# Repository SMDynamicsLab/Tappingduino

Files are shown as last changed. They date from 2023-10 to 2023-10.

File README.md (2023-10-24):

# Tappingduino
## A versatile shield for paced finger tapping experiments with Arduino

Paula Caral [1], Tomás Correa Morales [1], Paz García Lodi Fe [1], Ariel D. Silva [2,4], Ulises Bussi [2], Ignacio Spiousas [3,4], and Rodrigo Laje [2,4]

[1] Departamento de Física, FCEN, Universidad de Buenos Aires, Argentina  
[2] Laboratorio de Dinámica Sensomotora, Departamento de Ciencia y Tecnología, Universidad Nacional de Quilmes, Argentina  
[3] Laboratorio del Tiempo y la Experiencia, Universidad de San Andrés, Argentina  
[4] CONICET, Argentina

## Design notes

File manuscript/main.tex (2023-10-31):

    \documentclass[twocolumn]{article}

\usepackage{amsmath}
\usepackage{amssymb}
\usepackage{graphicx}
\usepackage{float}
\usepackage{bm}
\usepackage{wrapfig}
\usepackage{hyperref}
\usepackage{authblk}
\usepackage[backend=biber, sorting=none, style=numeric-comp]{biblatex}
\addbibresource{biblio.bib}

\title{Tappingduino: A versatile shield for paced finger tapping experiments with Arduino}
\author[1]{Paula Caral}
\author[1]{Tomás Correa Morales}
\author[1]{Paz García Lodi Fe}
\author[2,4]{Ariel D. Silva}
\author[2]{Ulises Bussi}
\author[3,4]{Ignacio Spiousas}
\author[2,4]{Rodrigo Laje}
\affil[1]{\small Departamento de Física, FCEN, Universidad de Buenos Aires, Argentina}
\affil[2]{Laboratorio de Dinámica Sensomotora, Departamento de Ciencia y Tecnología, Universidad Nacional de Quilmes, Argentina}
\affil[3]{Laboratorio del Tiempo y la Experiencia, Universidad de San Andrés, Argentina}
\affil[4]{CONICET, Argentina}

\date{\today}

\begin{document}

\maketitle

\begin{abstract}
Paced finger tapping is the simplest task to study sensorimotor synchronization (SMS), that is the mostly specifically human behavior of synchronizing motor actions to an external metronome \cite{Bavassi2013,Bavassi2017,Repp2005,Repp2013}.

In this work we show the design and construction of an Arduino shield for paced finger-tapping experiments. The pin footprint is compatible with Arduino Mega 2560 \cite{arduinomega}.
\end{abstract}

\section{System specifications}

The device is intended to be versatile and to allow many different types of experimental conditions, all related to the paced finger-tapping task.

\begin{description}
    \item[Independent audio channels.] Auditory stimuli are extensively used in finger tapping experiments. This device would allow experiments with dichotic auditory stimuli, not only for the study of time processing in healthy subjects \cite{Piazza1977} but also for the study of several perceptual and motor disorders \cite{Hugdahl1989}, cognitive impairments, and diseases \cite{Sebaiti2022}.

    \item[Sound timbre.] Control of sound quality or timbre is important in some experimental designs, for example choosing the sound waveform to be a square wave, a sinusoidal wave, etc.

    \item[Noise masking.] In order to better control the auditory feedback from the tap itself it is important to have good quality headphones, and use noise masking. White noise generation capabilities are thus desirable.
    
    \item[Virtual ground.] Arduino is a single-supply device, that is it only uses 0 and 5 V supply rails. Audio signals, however, oscillate above and below a reference. A virtual ground is thus needed at a value of approximately 2.5 V to allow the audio signals to oscillate around it.
    
    \item[Force sensor.] Responses are detected by a force-sensitive resistor (FSR). Some experimental designs need two of them \cite{Versaci2021} so this is also a requirement.
    
    \item[Visual stimuli.] Experimental designs to study sensory and sensorimotor integration need the stimuli to have at least two different modalities. This is why we included two LEDs in the device.

    \item[Temporal alignment.] Simultaneous recording of EEG data is now very usual in finger tapping experiments. A connector is included to allow a one-way, 3-bit alignment signal between Arduino and a second recording device.

    \item[Servo driving.] Some experimental designs include {\em spatial} perturbations in addition to the usual temporal ones \cite{Lopez2019}. This is why we include connectors to drive two servos.
\end{description}

\section{Hardware}

\subsection{Circuit design}

We designed the circuit under the constraint that all op amps should be single-supply (LM324) so the shield is fully compatible with the voltage range of Arduino. There are several technical reports available with recommendations and design criteria for single-supply op amp circuits \cite{singlesupply2000}.

We used Eagle, a well-known electronic design automation software for schematic creation and editing, auto-routing, and PCB layout. The circuit was tested on protoboard before printing and soldering. Figure \ref{fig.schematic} shows the circuit schematic.

\subsubsection{Virtual ground}

Block 1 in Figure \ref{fig.schematic} is a standard design of a virtual ground: a voltage divider with an op amp in a follower configuration \cite{singlesupply2000}. This allows us to decouple the voltage divider from the rest of the circuit (ideal voltage divider). An additional capacitor helps filtering out high-frequency noise.

\subsubsection{Independent audio channels}

Block 2 in Figure \ref{fig.schematic} contains the two independent audio channels A and B (left and right, respectively). Each channel has an op amp in a variable-gain, summing amplifier configuration. Each summing amplifier has three inputs corresponding to stimulus, feedback, and noise. Each input signal comes from a different output pin in the Arduino and enters a voltage divider prior to the summing amplifier to prevent saturation. The variable gain is controlled by a dual potentiometer and allows the subject to adjust the sound volume. The reference voltage for the summing amplifier is virtual ground. Resistor values were chosen so that the impedance at each stage in the chain divider-summing-amplifier is an order of magnitude greater than the previous stage (10 k$\Omega$, 100 k$\Omega$, 1 M$\Omega$), thereby reducing unwanted currents and voltage drops.

\subsubsection{Alignment, visual stimuli, and servos}

Block 3 in Figure \ref{fig.schematic} includes a 3-pin connector for sending a temporal alignment signal to other devices, two LEDs for the delivery of visual stimuli, and two 3-pin connectors for driving two servos.

\subsubsection{Force sensors}

Block 4 in Figure \ref{fig.schematic} shows the connectors for the two force sensors. Each sensor has a potentiometer (trimpot) to adjust the circuit's sensitivity so it can either detect a soft tap (i.e.\ a low-voltage signal) or prevent a strong tap from saturating (i.e.\ a high-voltage signal).

\subsubsection{Low-pass filtering}

We decided not to include a low-pass filter due to space constraints: two additional op amps would be needed (one for each audio channel), meaning a whole additional integrated circuit plus its connections, in addition to resistors and capacitors. As shown below (Figure \ref{fig.BRDCompleto}), the PCB is already very crowded for hand soldering and a double-sided copper-clad laminate was necessary to accommodate all traces. However, noise generation capabilities are included as described above; in case noise is desired, an external low-pass filter should be added between the audio output of the shield and the headphones.

\begin{figure*}[!ht]
    \centering
    
    \caption{Circuit schematic. Block 1: virtual ground. Block 2: independent audio channels. Block 3: temporal alignment, visual stimuli, and servo driving. Block 4: force sensor connectors. Pin A11 is used as analog input to record the actual value of virtual ground and making it available to the code.}
    \label{fig.schematic}
\end{figure*}

\begin{figure*}[!ht]
    \centering
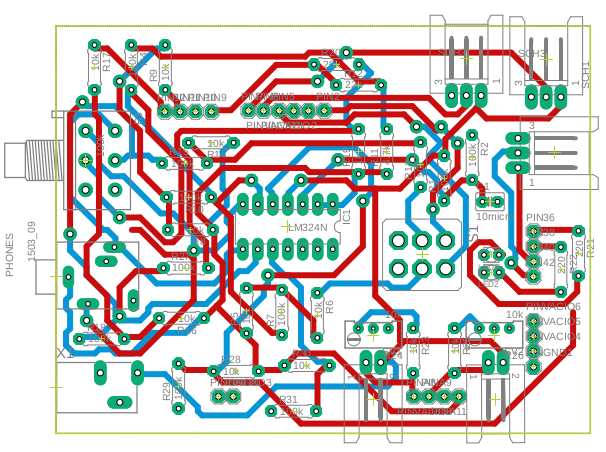
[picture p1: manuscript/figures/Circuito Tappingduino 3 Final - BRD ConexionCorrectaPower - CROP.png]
    
    \caption{PCB layout. Red traces: top layer, blue traces: bottom layer. Ground planes not shown.}
    \label{fig.BRDCompleto}
\end{figure*}

\subsection{PCB design}

Components were initially located based on a trade-off among several criteria: proximity to corresponding Arduino pins, proximity among related components, simplicity and accessibility for the user, and simplicity for soldering. We decided to use a double-sided copper-clad laminate. We took into account the following specific considerations:

\begin{description}
    \item[Soldering to a specific layer.] Some components have very short legs and are very difficult to solder to the layer where they sit due to potential damage to the component. For instance, in the top layer: switches, op amps sockets, potentiometers, female miniplug connectors, and trimpots; in the bottom layer: pins to connect to Arduino. That is why we constrained the auto-routing to prevent a trace to reach any of these components on the same layer (polygons in tRestrict and bRestrict in Eagle).
    
    \item[Forbidden regions for vias.] Vias are connections between the two copper layers. Components that sit close to the layer are difficult to solder when they have a via beneath them, so we defined polygons (vRestrict) to prevent the location of vias beneath components (other than regular resistors).
    
    \item[Central connector in Arduino.] Arduino Mega 2560 has a six-pin connector in the middle, so any soldering in the bottom layer could potentially make electrical contact with it. To avoid this we placed a bRestrict polygon thus preventing any component or connection to be located there.
    
    \item[Extra pins for better structural stability.] We added several pins with no electrical function in order to have a better union between Arduino and the shield.
    
    \item[Size of pads and vias.] To make drilling and soldering easier we increased the size of pads and vias.
    
    \item[Ground planes.] We covered empty spaces in both layers with polygons connected to ground for easier routing and reducing electrical noise and interference.
    
    \item[Isolation of vias.] Vias connected to the ground plane were termically isolated to prevent loss of heat during soldering.
    
    \item[Size of laminate.] The size of the copper-clad laminate was increased beyond the size of the Arduino to give Eagle a little more room to route traces.
\end{description}

Figure \ref{fig.BRDCompleto} shows the final design of the PCB. We attempted several different initial distribution of components and several auto-routings each, and chose the one that maximized the completion percentage and minimized the number of vias to simplify soldering. Figure \ref{fig.HardwareFinal} shows the actual finished shield.

\begin{figure*}[!ht]
    \centering
%    \includegraphics[width=0.75\linewidth]{figures/CircCollage_conCarteles.png}
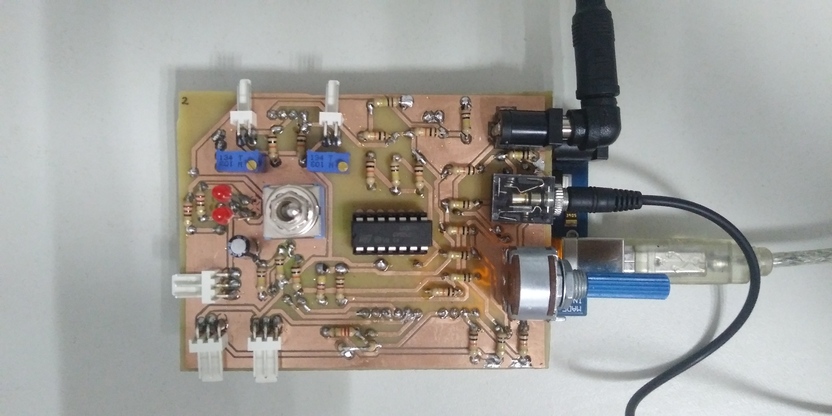
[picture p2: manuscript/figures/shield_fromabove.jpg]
    
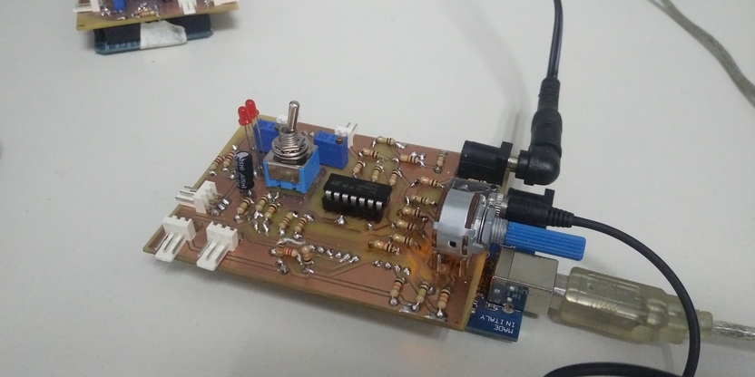
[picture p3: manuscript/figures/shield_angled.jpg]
    
    \caption{Actual finished shield, plugged on top of Arduino.}
    \label{fig.HardwareFinal}
\end{figure*}

\section{Software}

\subsection{Flow control}

The experimental unit in a typical finger tapping experiment is the trial, where the subject is exposed to a sequence of consecutive 30-45 brief stimuli. Trials are separated by pauses, and are grouped in blocks. A full experiment is a few blocks long.

The general control of flow during the experiment is performed by an experiment controller written in Python, while the control during a trial switches to the Arduino code in C. The experiment controller and the trial controller communicate to each other with text messages via the Serial port: the experiment controller sends the current trial parameters (interstimulus interval, number of stimuli, perturbation size, etc.), the trial controller records a trial and sends back the trial data (e.g. response times).

\subsection{Trial controller and Arduino timers}
\label{sec.timers}

We based our Arduino software development on Taparduino \cite{Schultz2016}.

One of the main functions of the Arduino-shield duo is producing sound, that is an analog voltage signal. However, the output pins in Arduino are only capable of having digital values (either HIGH or LOW), so a technique called pulse width modulation (PWM) is needed, where the pin is switched between HIGH and LOW at a high frequency with a variable duty cycle. The averaging over many oscillations leads to a continuous mean value depending on the duty cycle (close to LOW for a small duty cycle, or close to HIGH for a large duty cycle).

PWM is performed via timers, which are dedicated internal clocks/counters that operate in parallel with the central processor and can execute small portions of code on an interrupt basis. Timers in all operation modes work by counting from 0 through $2^b-1$, where $b$ is the number of bits of the timer, at a frequency $f_{\mbox{\scriptsize timer}} = 16\,\mbox{MHz}/2^b$, where 16 MHz is the oscillation frequency of the crystal in Arduino. Once counting reaches its TOP value it overflows and starts over again. The counting frequency can be modified by setting prescalers according to eq.\ \ref{ec.prescaling} \cite{arduinomanual}:
\begin{equation}
    f_{\mbox{\scriptsize timer}} = \frac{16\,\mbox{MHz}}{N \cdot 256}
    \label{ec.prescaling}
\end{equation}

\noindent Prescaler $N$ can take values $N=1,8,16,\dots$.

Every timer has two channels each associated with a different output pin, and can have different duty cycles. We used timers to generate sounds corresponding to stimuli and (optional) auditory feedback from the taps, and to generate masking noise. The appropiate timer configuration is known as FastPWM (with reset on overflow) and is shown in Figure \ref{fig.FastPWM} \cite{TimersOVF}.

\begin{figure}[ht]
    \centering
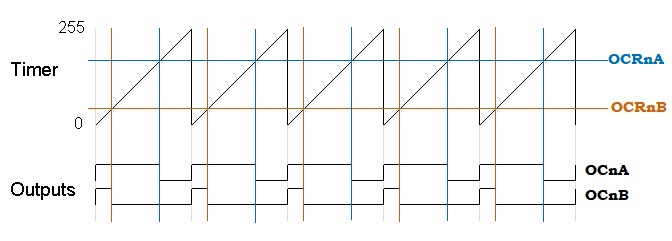
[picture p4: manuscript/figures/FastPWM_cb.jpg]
    
    \caption{Timing diagram of a timer in 8-bit Fast PWM mode. The timer counts from 0 through 255 where it overflows and executes an interrupt. Registers OCRnA and OCRnB determine the duty cycle of each channel. Reproduced from \cite{TimersOVF}}
    \label{fig.FastPWM}
\end{figure}

We chose timers 1 and 3 for stimulus and feedback, respectively, and their channels A and B for left and right audio channels, respectively. Registers OCR1A and OCR1B determine the duty cycle of each channel in timer 1 (OCR3A and OCR3B for timer 3) and can be set independently. This allows us to send different audio signals to either ear. Timers 1 and 3 are 16-bit timers and can be set in 9-bit Fast PWM mode, which sets the interrupt frequency at approximately 31 kHz. This allows us to produce sound with an acceptable quality up to a fundamental frequency of around 2 kHz.

We used timer 2 to generate noise. Timer 2 has less resolution than timers 1 and 3 (it is an 8-bit timer) but quality is not as important in this case.

\subsection{Sound production}
\label{sec.sonido}

An analogous sound wave can be produced by a digital output by means of PWM: the digital output is switched between HIGH and LOW at a high frequency with a variable duty cycle, and then a low-pass filter with an appropriate cutoff frequency leads to a smoothed version of the signal whose mean value tracks the duty cycle \cite{arduinofading}. Figure \ref{fig.PWMsine} shows how a square wave with a time-varying duty cycle leads to a smooth low-pass filtered sinusoidal curve.

\begin{figure}[ht]
    \centering
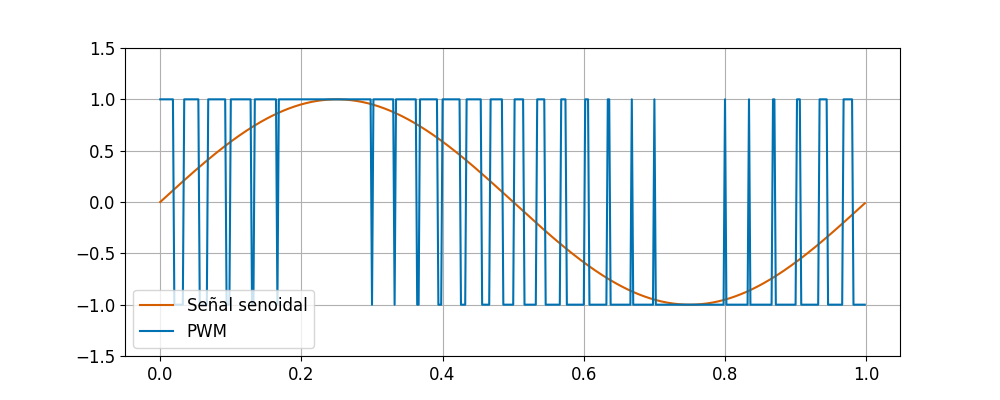
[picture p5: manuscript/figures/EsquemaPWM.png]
    
    \caption{PWM with a relatively slowly varying duty cycle (blue curve) followed by low-pass filtering can produce a smooth sinusoidal signal with a well-defined frequency (orange curve).}
    \label{fig.PWMsine}
\end{figure}

The frequency of the sinusoidal is determined by the frequency of the duty cycle, and this in turn is set in the following way. Every time the timer overflows we set a new OCRnX value according to a lookup table with values that uniformly sample one period of the desired waveform, such that the duty cycle follows it. Figure \ref{fig.TablaSenoCompletay440} shows the contents of the lookup table for a sinusoidal waveform (orange curve). The actual frequency of the duty cycle (and thus of the sound signal) can be chosen by down- or up-sampling the lookup table. Down-sampling (by skipping values) leads to higher frequencies, while up-sampling (by repeating values) leads to lower frequencies. Either way can be detrimental to sound quality if excessive. When up-sampling, quality can be improved by interpolating (instead of just repeating values) but that would increase the load on the micro-controller so a trade-off analysis would be needed.

The blue curve in Figure \ref{fig.TablaSenoCompletay440} corresponds to down-sampling the lookup table to get a 440 Hz sinusoidal waveform. The lookup table is down-sampled by selecting values separated by a fixed quantity called the {\em frequency tuning word} (FTW):

\begin{equation}
    FTW = \frac{f_{\mbox{\scriptsize out}} \times 2^{32}}{f_{\mbox{\scriptsize timer}}}
\end{equation}

\noindent where $f_{\mbox{\scriptsize out}}$ is the desired output frequency in Hz, $2^{32}$ is the resolution of the phase accumulator, and $f_{\mbox{\scriptsize timer}}$ is the timer frequency in Hz \cite{ftw}.

\begin{figure}[ht]
    \centering
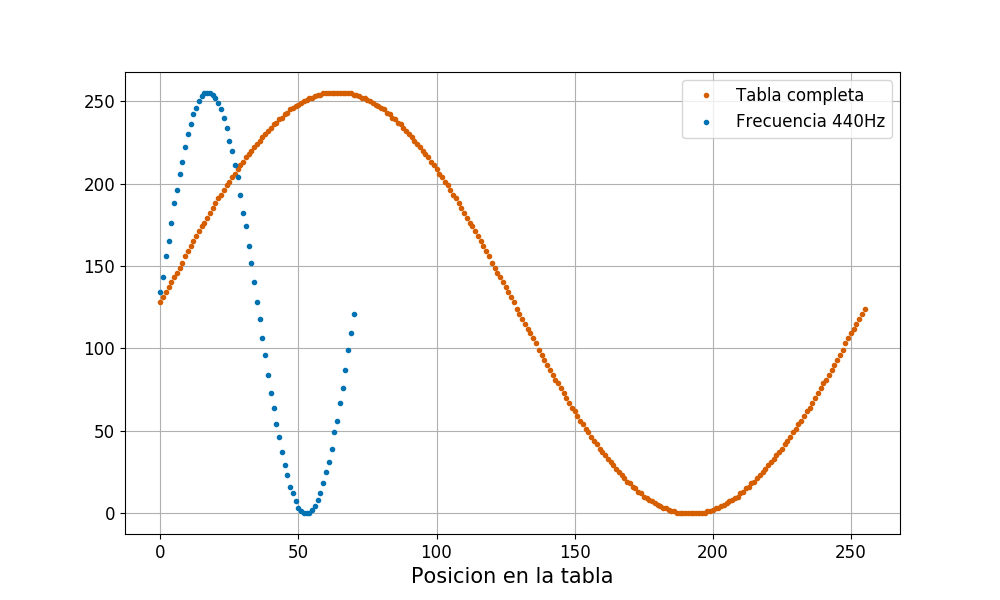
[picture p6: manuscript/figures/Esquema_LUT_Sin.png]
        
        \caption{Contents of the lookup table for a sinusoidal waveform (orange), and down-sampling to a frequency of 440 Hz (blue).}
        \label{fig.TablaSenoCompletay440}
\end{figure}

\subsection{Noise generation}
\label{sec.noise}

We generate noise by randomly switching the PWM duty cycle such that the low-pass filtered signal randomly oscillates around virtual ground. A noise amplitude is defined with value up to half the TOP value of the timer, and a number of overflow periods is pseudorandomly chosen by a lightweight linear-feedback shift register \cite{galoisLFSR} (range 2-4). The duty cycle is set at a value equal to virtual ground + amplitude for the chosen number of periods, then reset to virtual ground - amplitude for the same number of periods, and then the number of periods is newly chosen to start over. In this way the noise power spectrum is relatively independent of the chosen amplitude.

\section{Open software and hardware}

Code for the experiment controller in Python and the trial controller in C, and .sch and .brd Eagle files for the circuit schematic and PSB are available in the following GitHub repository: \url{https://github.com/SMDynamicsLab/Tappingduino}.

\printbibliography

\end{document}

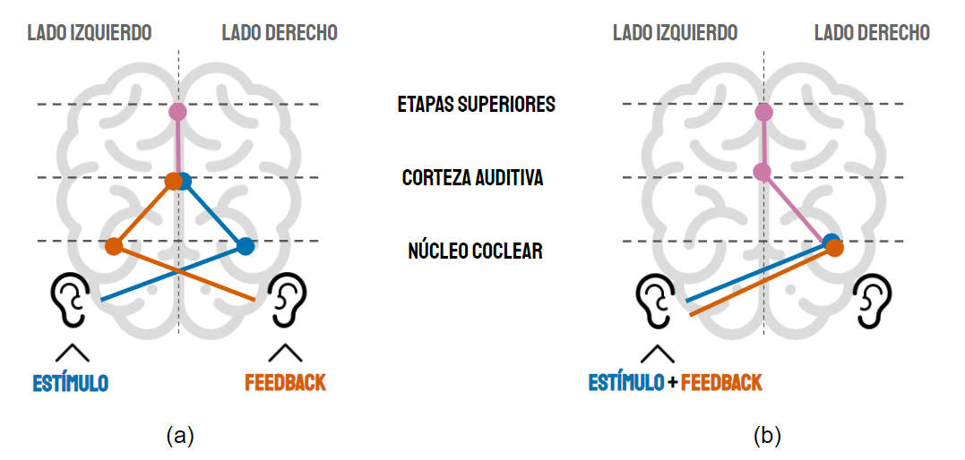
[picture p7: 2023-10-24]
manuscript/figures/esquema4.png

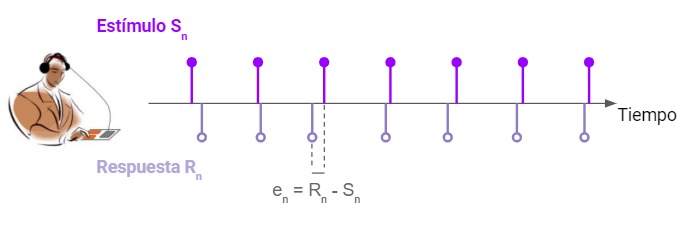
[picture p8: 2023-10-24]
manuscript/figures/esquema1a.png

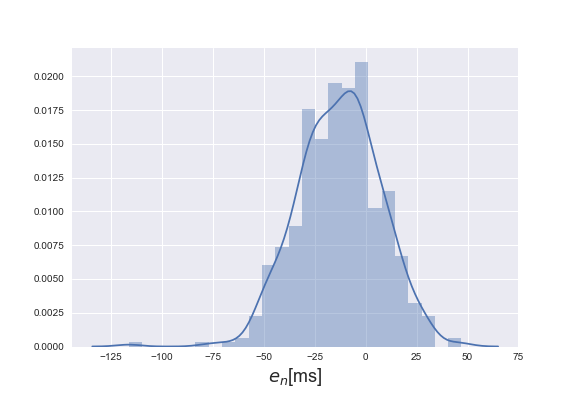
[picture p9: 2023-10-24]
manuscript/figures/esquema1c.png

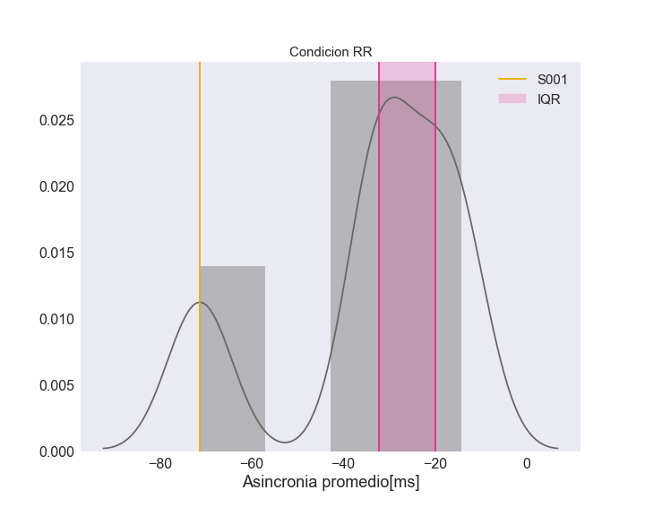
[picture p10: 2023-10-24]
manuscript/figures/DistribAsinc_CondRR.png

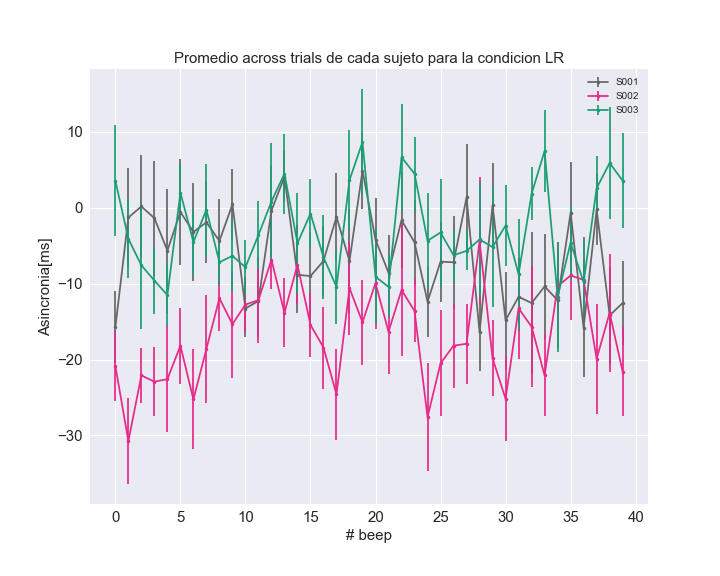
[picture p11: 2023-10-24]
manuscript/figures/mean_across_trials_LR.png

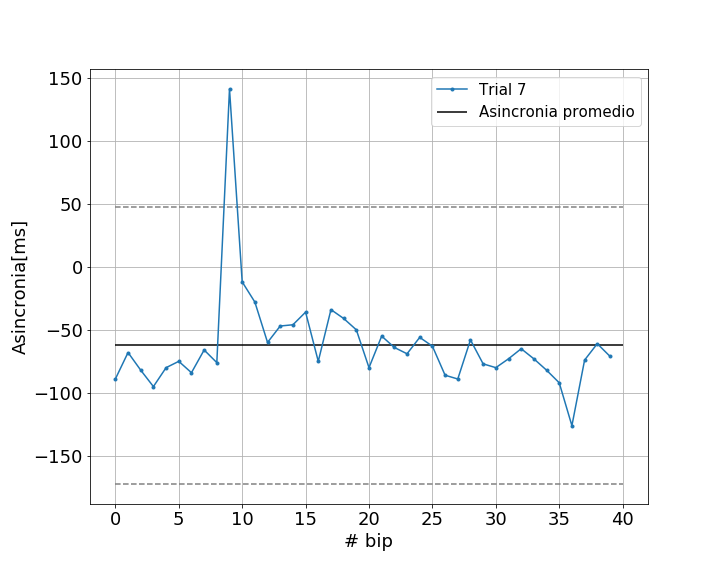
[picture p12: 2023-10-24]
manuscript/figures/trials_outliers_S001_RR_Trial7.png

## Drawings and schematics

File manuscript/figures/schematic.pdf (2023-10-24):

# Bloque 1

# Bloque 3

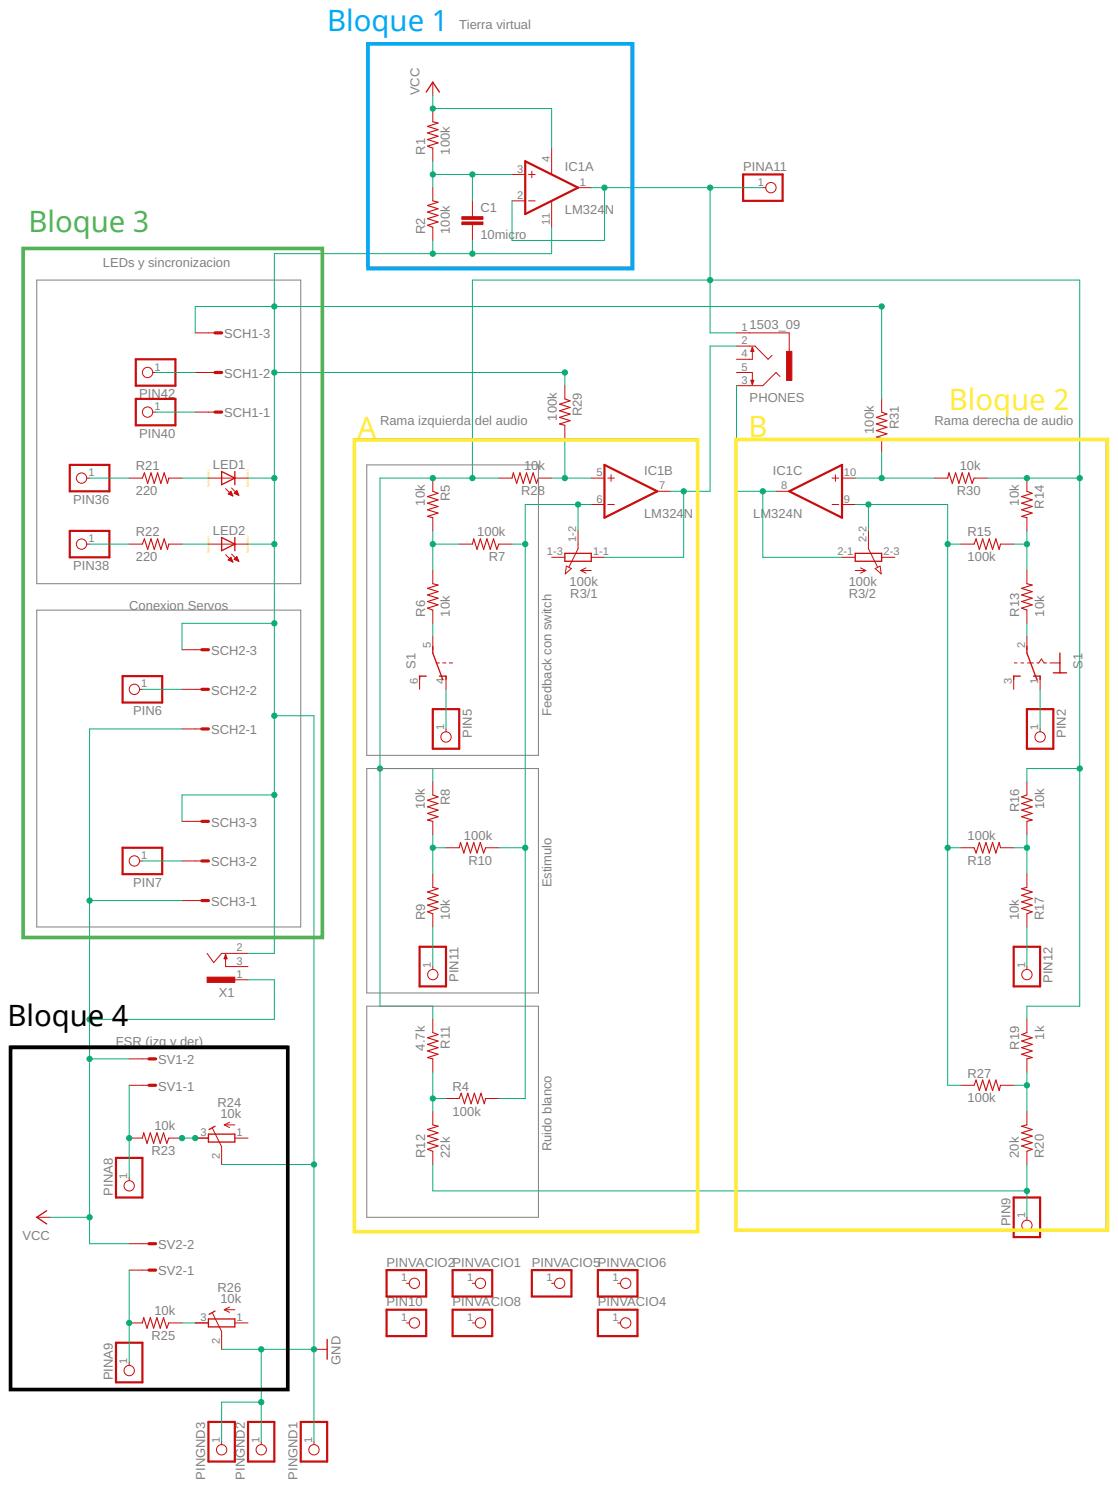
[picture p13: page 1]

Feedback con switch Estimulo Ruido blanco

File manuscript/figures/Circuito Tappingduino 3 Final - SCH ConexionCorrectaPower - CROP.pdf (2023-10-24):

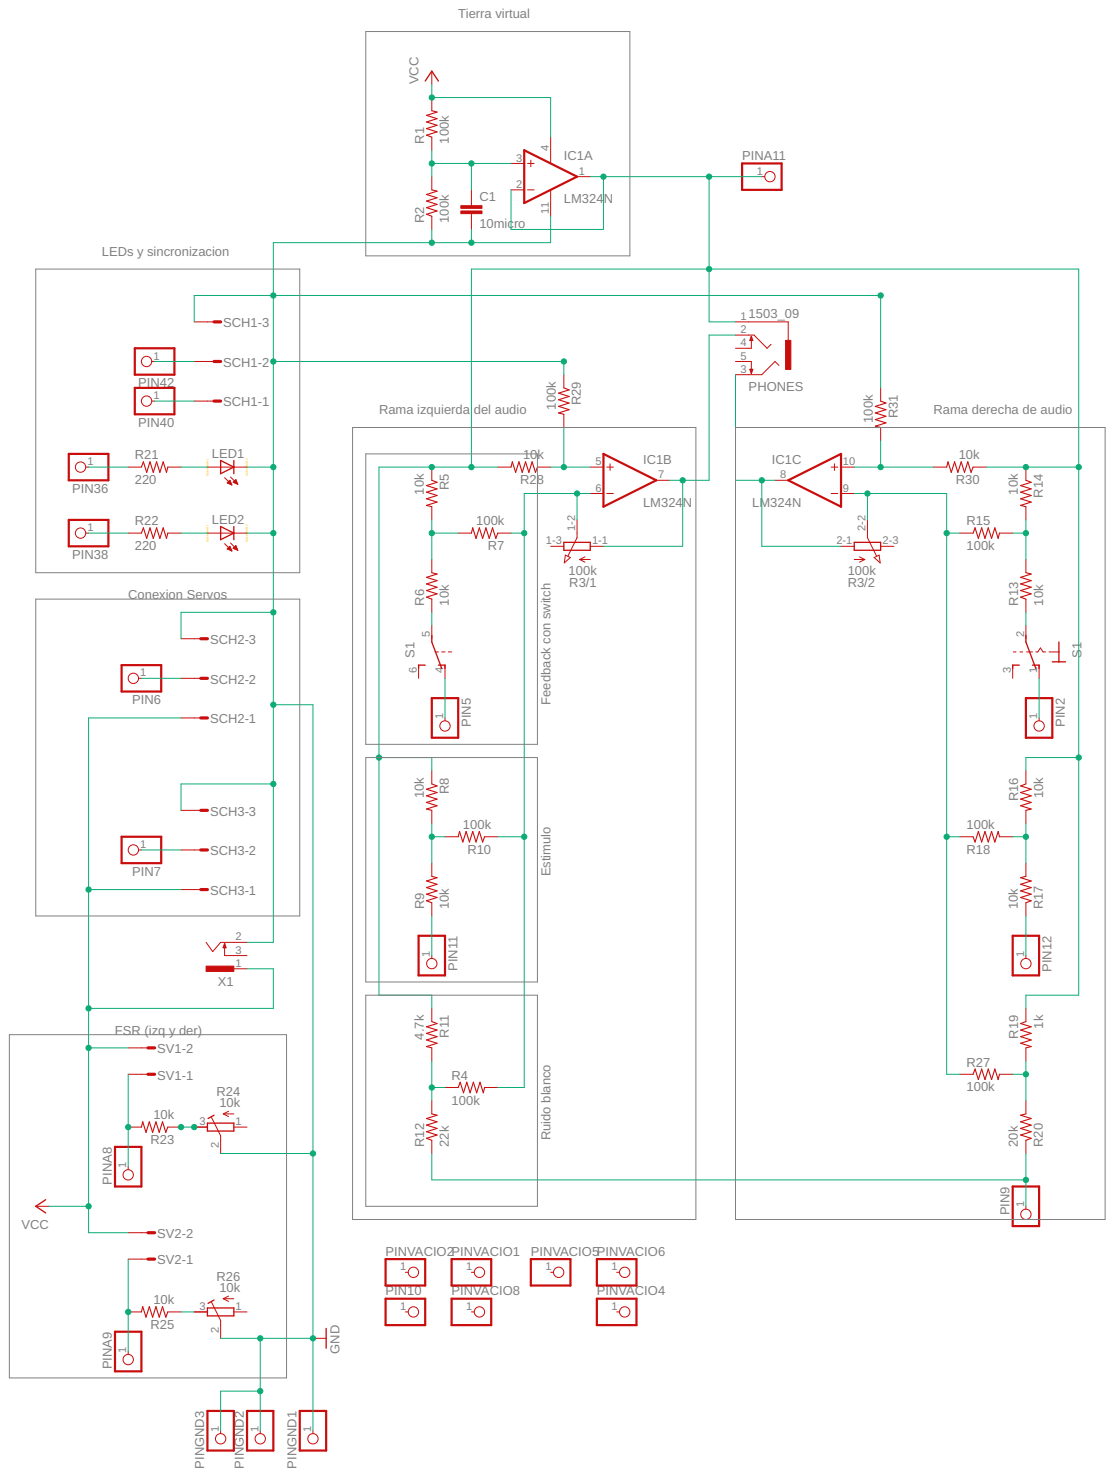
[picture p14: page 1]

Feedback con switch Estimulo Ruido blanco

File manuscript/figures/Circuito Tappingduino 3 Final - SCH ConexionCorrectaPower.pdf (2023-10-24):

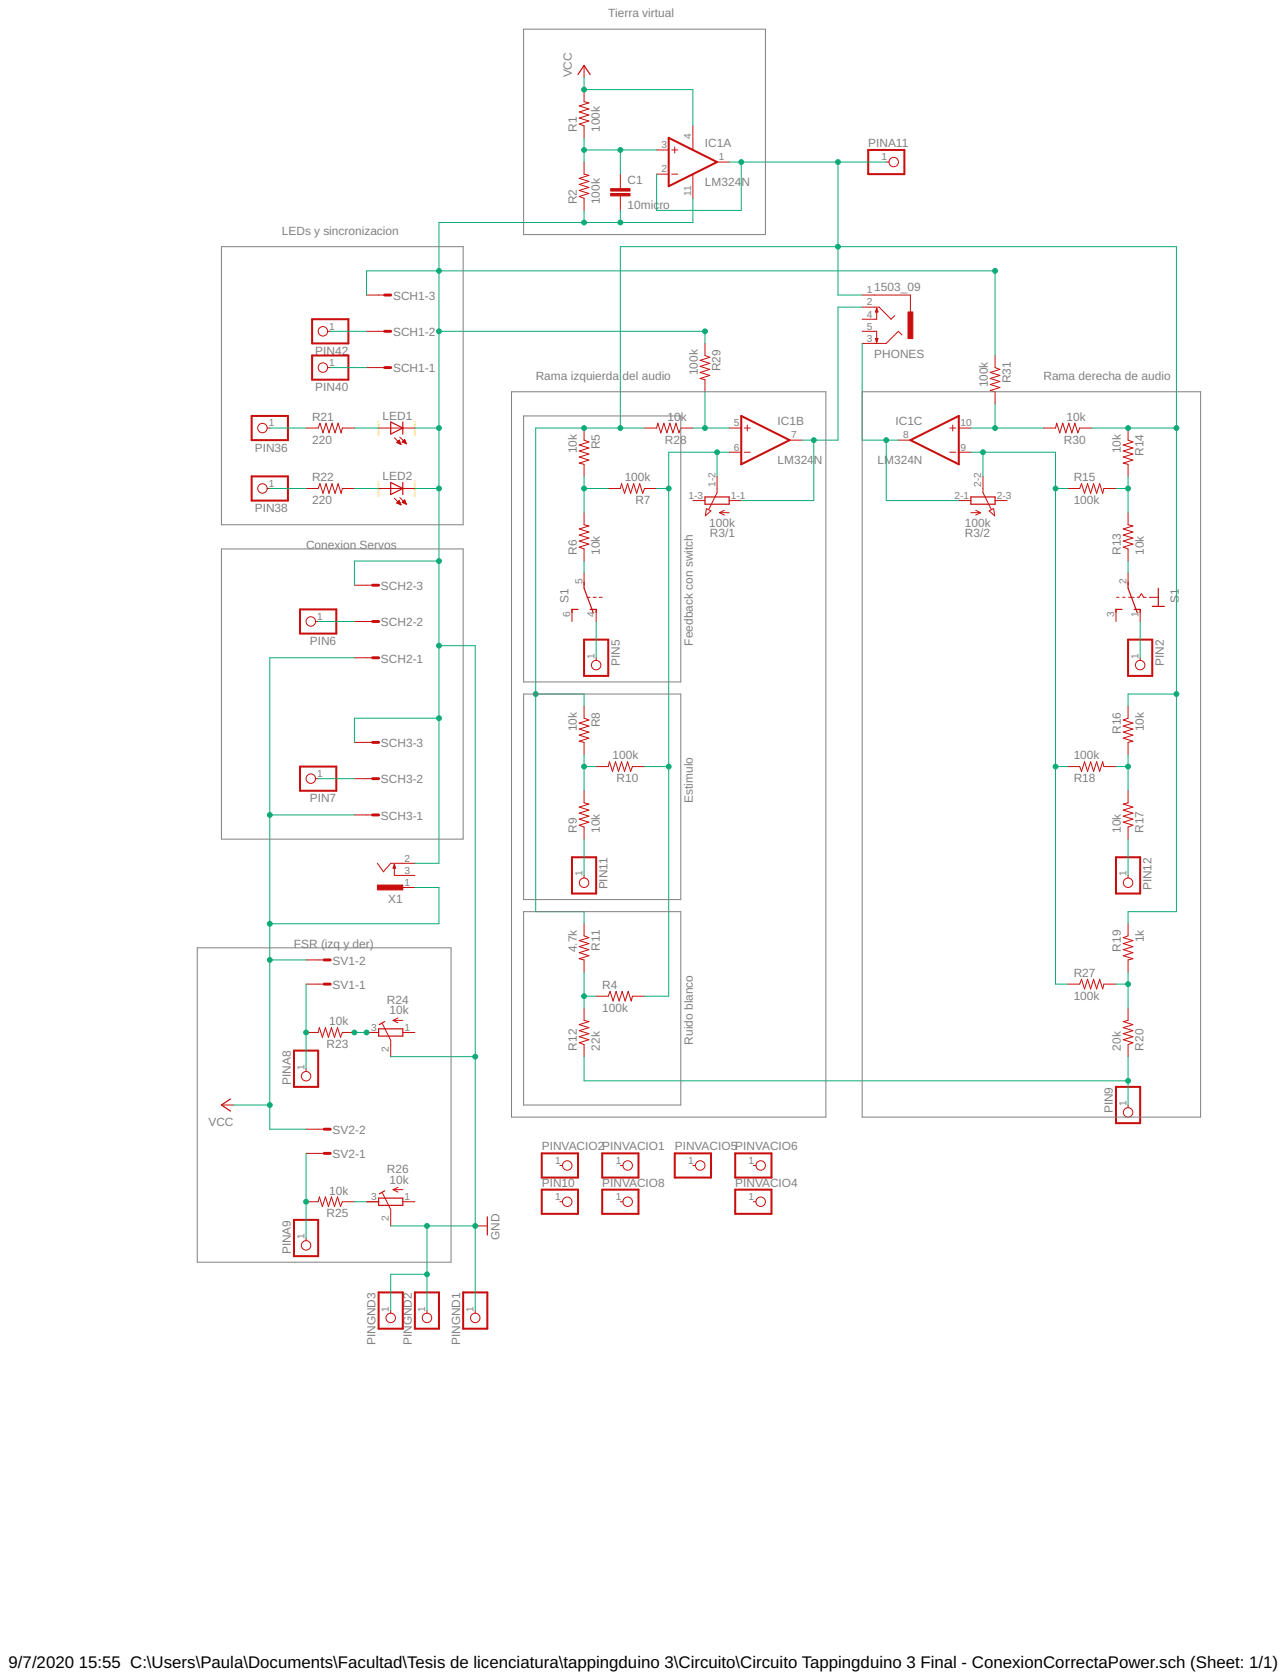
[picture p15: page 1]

Feedback con switch Estimulo Ruido blanco

9/7/2020 15:55 C:\Users\Paula\Documents\Facultad\Tesis de licenciatura\tappingduino 3\Circuito\Circuito Tappingduino 3 Final - ConexionCorrectaPower.sch (Sheet: 1/1)

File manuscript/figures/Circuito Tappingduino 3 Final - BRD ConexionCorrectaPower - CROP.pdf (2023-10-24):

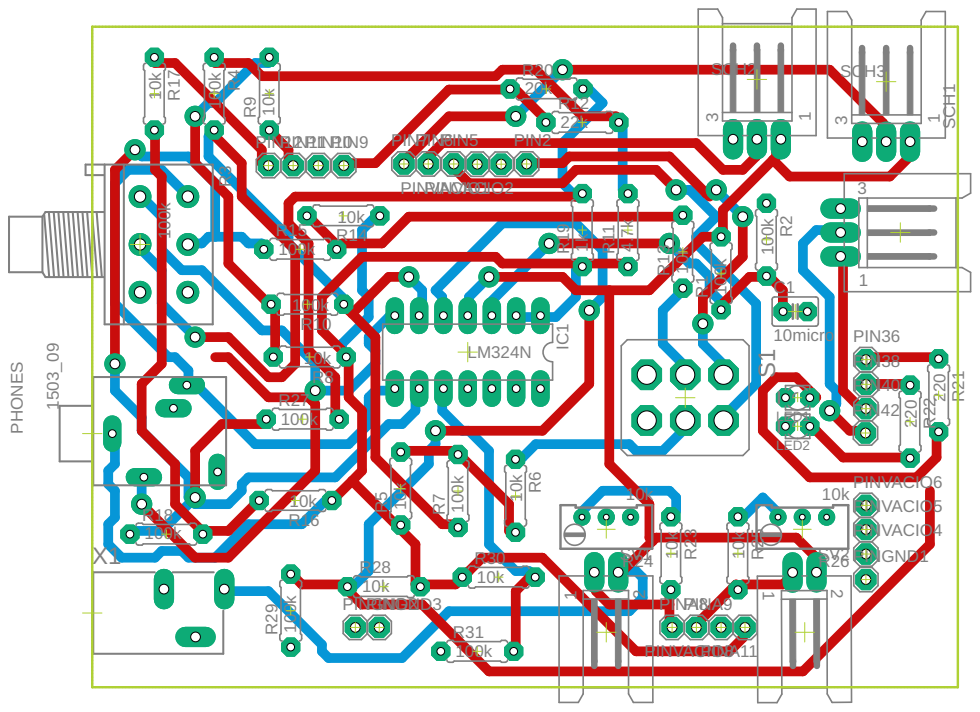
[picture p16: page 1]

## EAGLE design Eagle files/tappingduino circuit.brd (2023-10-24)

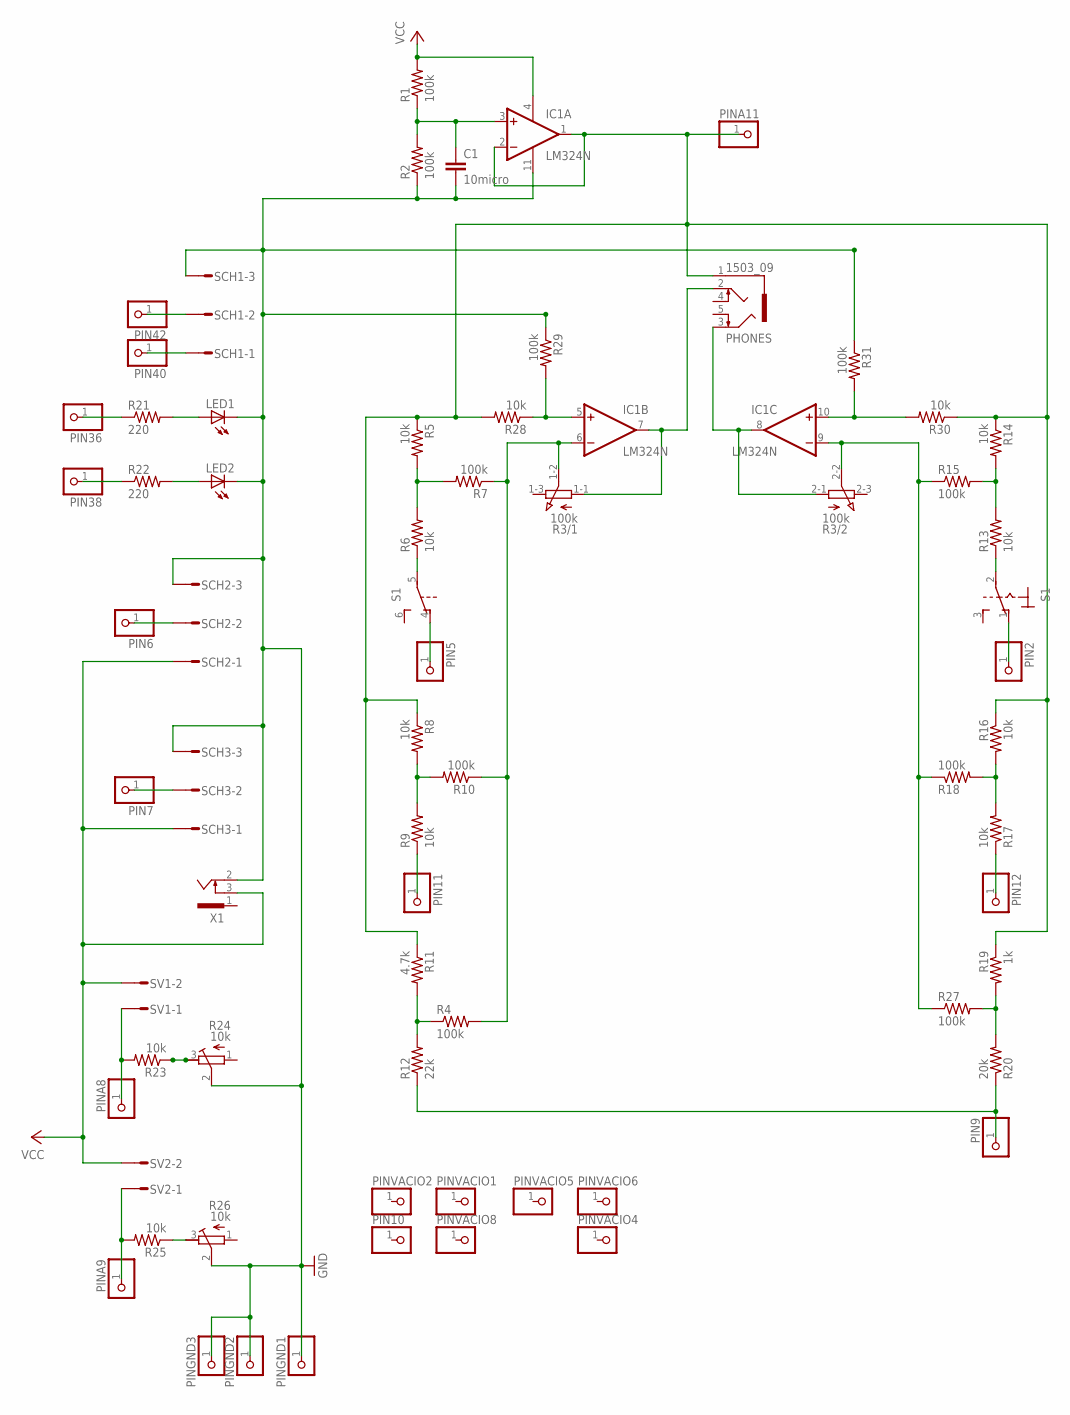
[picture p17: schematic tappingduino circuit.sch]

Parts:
C1: 10micro; C025-030X050
IC1: LM324N; DIL14
LED1, LED2: LED_ELD260; LED_LD260
PHONES: 1503_09
PIN2, PIN5, PIN6, PIN7, PIN9, PIN10, PIN11, PIN12, PIN36, PIN38, PIN40, PIN42: PINHD-1X1; 1X01
PINA8, PINA9, PINA11: PINHD-1X1; 1X01
PINGND1, PINGND2, PINGND3: PINHD-1X1; 1X01
PINVACIO1, PINVACIO2, PINVACIO4, PINVACIO5, PINVACIO6, PINVACIO8: PINHD-1X1; 1X01
R1, R2, R4, R7, R10, R15, R18, R27, R29, R31: 100k; 0207/7
R3: 100k; 3RP/1610G
R5, R6, R8, R9, R13, R14, R16, R17, R23, R25, R28, R30: 10k; 0207/7
R11: 4.7k; 0207/7
R12: 22k; 0207/7
R19: 1k; 0207/7
R20: 20k; 0207/7
R21, R22: 220; 0207/7
R24, R26: 10k; RTRIM64W
S1: 320-938
SCH1, SCH2, SCH3: L03P
SV1, SV2: L02P
X1: SCD-014A; SCD-014-A

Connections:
GND: C1.2, IC1.11 (V-), LED1.K (C), LED2.K (C), PINGND1.1, PINGND2.1, PINGND3.1, R2.1, R24.2 (S), R26.2 (S), R29.1, R31.1, SCH1.3, SCH2.3, SCH3.3, X1.2
unnamed: C1.1, IC1.3 (+IN), R1.1, R2.2
unnamed: R25.1, R26.3 (E)
unnamed: PIN11.1, R9.1
unnamed: IC1.6 (-IN), R3.1-2 (S), R4.2, R7.1, R10.1
unnamed: R5.2, R6.2, R7.2
unnamed: R6.1, S1.5
unnamed: PIN5.1, S1.4 (O)
unnamed: IC1.1 (OUT), IC1.2 (-IN), PHONES.1, PINA11.1, R5.1, R8.1, R11.1, R14.1, R16.1, R19.1, R28.2, R30.1
unnamed: R8.2, R9.2, R10.2
unnamed: IC1.10 (+IN), R30.2, R31.2
unnamed: R4.1, R11.2, R12.2
unnamed: IC1.9 (-IN), R3.2-2 (S), R15.1, R18.1, R27.1
unnamed: R13.2, R14.2, R15.2
unnamed: R13.1, S1.2
unnamed: PIN2.1, S1.1 (O)
unnamed: IC1.5 (+IN), R28.1, R29.2
unnamed: R19.2, R20.2, R27.2
unnamed: R16.2, R17.2, R18.2
unnamed: PIN12.1, R17.1
unnamed: PIN9.1, R12.1, R20.1
unnamed: PIN42.1, SCH1.2
unnamed: PIN40.1, SCH1.1
unnamed: LED1.A, R21.2
unnamed: PIN36.1, R21.1
unnamed: LED2.A, R22.2
unnamed: PIN38.1, R22.1
unnamed: PIN7.1, SCH3.2
unnamed: PIN6.1, SCH2.2
unnamed: IC1.8 (OUT), PHONES.3, R3.2-1 (A)
unnamed: PINA8.1, R23.2, SV1.1
unnamed: R23.1, R24.3 (E)
unnamed: PINA9.1, R25.2, SV2.1
unnamed: IC1.7 (OUT), PHONES.2, R3.1-1 (A)
VCC: IC1.4 (V+), R1.2, SCH2.1, SCH3.1, SV1.2, SV2.2, X1.3

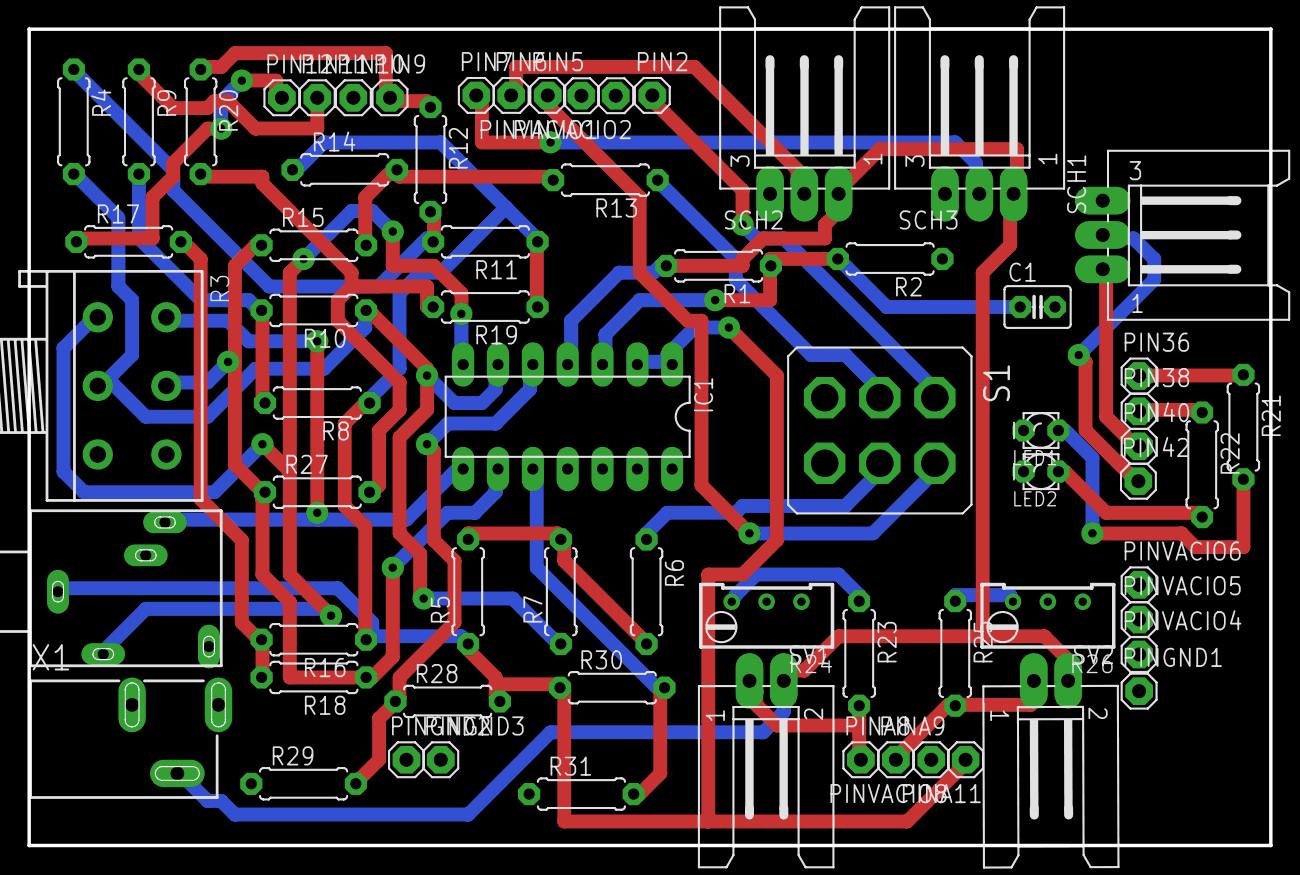
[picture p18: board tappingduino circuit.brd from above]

Board: 2 copper layers, 90.5 x 59.5 mm, 67 parts (0 on the bottom side), 35 nets.

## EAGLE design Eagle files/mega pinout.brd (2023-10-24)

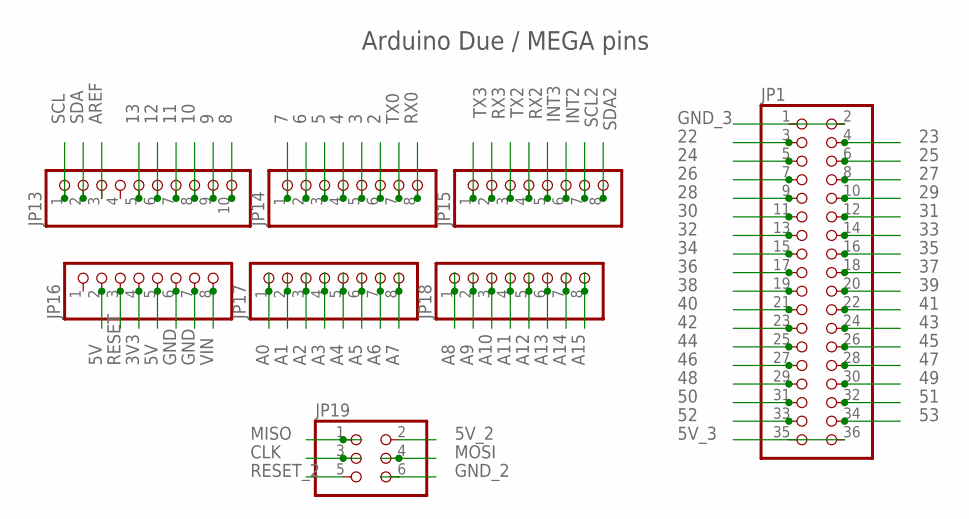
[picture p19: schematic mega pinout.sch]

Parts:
JP1: PINHD-2X18; 2X18
JP13: PINHD-1X10; 1X10
JP14, JP15, JP16, JP17, JP18: PINHD-1X8; 1X08
JP19: PINHD-2X3; 2X03

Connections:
2: JP14.6
3: JP14.5
3V3: JP16.4
4: JP14.4
5: JP14.3
5V: JP16.2, JP16.5
5V_2: JP19.2
5V_3: JP1.36
6: JP14.2
7: JP14.1
8: JP13.10
9: JP13.9
10: JP13.8
11: JP13.7
12: JP13.6
13: JP13.5
22: JP1.3
23: JP1.4
24: JP1.5
25: JP1.6
26: JP1.7
27: JP1.8
28: JP1.9
29: JP1.10
30: JP1.11
31: JP1.12
32: JP1.13
33: JP1.14
34: JP1.15
35: JP1.16
36: JP1.17
37: JP1.18
38: JP1.19
39: JP1.20
40: JP1.21
41: JP1.22
42: JP1.23
43: JP1.24
44: JP1.25
45: JP1.26
46: JP1.27
47: JP1.28
48: JP1.29
49: JP1.30
50: JP1.31
51: JP1.32
52: JP1.33
53: JP1.34
A0: JP17.1
A1: JP17.2
A2: JP17.3
A3: JP17.4
A4: JP17.5
A5: JP17.6
A6: JP17.7
A7: JP17.8
A8: JP18.1
A9: JP18.2
A10: JP18.3
A11: JP18.4
A12: JP18.5
A13: JP18.6
A14: JP18.7
A15: JP18.8
AREF: JP13.3
CLK: JP19.3
GND: JP16.6, JP16.7
GND_3: JP1.2
INT2: JP15.6
INT3: JP15.5
MISO: JP19.1
MOSI: JP19.4
RESET: JP16.3
RESET_2: JP19.5
RX0: JP14.8
RX2: JP15.4
RX3: JP15.2
SCL: JP13.1
SCL2: JP15.7
SDA: JP13.2
SDA2: JP15.8
TX0: JP14.7
TX2: JP15.3
TX3: JP15.1
VIN: JP16.8

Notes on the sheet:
Arduino Due / MEGA pins

Board: 2 copper layers, 8 parts (0 on the bottom side), 2 nets, no tracks yet.

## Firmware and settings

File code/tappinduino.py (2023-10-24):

# -*- coding: utf-8 -*-
"""
Created on Thu Jul 21 13:47:59 2022

@author: RLaje, ASilva
"""

import numpy as np
import pandas as pd
import glob
import os


#%% Define Python user-defined exceptions.
class Error(Exception):
	"""Base class for other exceptions"""
	pass


#%% Condition_Dictionary
# Function to create the condition dictionary. Return a dataframe.
# perturb_type_dictionary --> dict. perturb_size_dictionary --> dict.
def Condition_Dictionary(perturb_type_dictionary, perturb_size_dictionary):

	condition_list = []
	condition_number_list = []
	perturb_type_list = []
	perturb_size_list = []
	
	index = 0
	for perturb_type in perturb_type_dictionary.keys():
		for perturb_size in perturb_size_dictionary.keys():
			condition_list.append(perturb_type + perturb_size)	
			condition_number_list.append(index)
			perturb_type_list.append(int(perturb_type_dictionary[perturb_type]))
			perturb_size_list.append(int(perturb_size_dictionary[perturb_size]))
			index = index + 1
	
	condition_dictionary_df = pd.DataFrame()
	condition_dictionary_df = condition_dictionary_df.assign(Name = condition_list, Condition = condition_number_list, 
								Perturb_type = perturb_type_list, Perturb_size = perturb_size_list)
	return condition_dictionary_df


#%% compute_asyn
# Compute asynchronies from stimulus and response time occurrences. Return a dataframe.
def Compute_Asyn(stim_times,resp_times):
	if len(resp_times)==0:
		asyn = []
		assigned_stim = []
	else:
		ISI = np.median(np.diff(stim_times))
		asyn_max = round(ISI/2)
		n_stims = len(stim_times)
		n_resps = len(resp_times)
		minima_R = np.zeros((n_stims,n_resps),dtype=int)
		minima_S = np.zeros((n_stims,n_resps),dtype=int)
		assigned_stim = -np.ones(n_resps,dtype=int)
		stimuli_flag = np.zeros(n_stims,dtype=int)
		asyn = np.full(n_resps,np.nan)
	
		# Find matching S-R pairs
	
		# pairwise differences between every response and every stimulus
		# (dimensions = number of stimuli x number of responses)
		differences = -np.subtract.outer(stim_times,resp_times).astype(float)	# type float so it can be NaN
		differences[abs(differences)>=asyn_max] = np.nan # remove differences larger than threshold
	
		# for every response, find the closest stimulus (nontrivial if more responses than stimuli)
		# IM SURE THIS LOOP CAN BE VECTORIZED
		for resp in range(n_resps):
			aux = differences[:,resp]
			# prevent "no non-missing arguments to min; returning Inf" warning
			#if np.any(np.isnan(aux)): # find at least one non-missing value
			min_abs = np.nanmin(abs(aux))
			min_idx = np.where(abs(aux)==min_abs)
			minima_R[min_idx,resp] = 1
	
	
		# remove multiple responses closest to a single stimulus (row-wise consecutive 1's)
		# i.e. make no attempt at deciding
		minima_shift_R = minima_R + np.roll(minima_R,(0,1),(0,1)) + np.roll(minima_R,(0,-1),(0,1))
		minima_R[np.where(minima_shift_R>=2)] = 0
	
		# for every stimulus, find the closest response (nontrivial if more stimuli than responses)
		# IM SURE THIS LOOP CAN BE VECTORIZED
		for stim in range(n_stims):
			aux = differences[stim,:]
			# prevent "no non-missing arguments to min; returning Inf" warning
			#if np.any(np.isnan(aux)): # find at least one non-missing value
			if all(np.isnan(aux)):
				min_abs = np.nan
			else:
				min_abs = np.nanmin(abs(aux))
			min_idx = np.where(abs(aux)==min_abs)
			minima_S[stim,min_idx] = 1
	
		# remove multiple stimuli closest to a single response (col-wise consecutive 1's)
		# i.e. make no attempt at deciding
		minima_shift_S = minima_S + np.roll(minima_S,(1,0),(0,1)) + np.roll(minima_S,(-1,0),(0,1))
		minima_S[np.where(minima_shift_S>=2)] = 0
	
		# matching pairs are represented by intersections (i.e. common 1's)
		minima_intersect = minima_R*minima_S
	
		# save asynchronies: get row and column for every matched pair
		SR_idxs = np.where(minima_intersect==1)
		S_idx = SR_idxs[0]
		R_idx = SR_idxs[1]
	
		# keep track of which stimulus was assigned to each response (-1 if not assigned)
		assigned_stim[R_idx] = S_idx
		# keep track of assigned stimuli (0 if not assigned)
		stimuli_flag[S_idx] = np.ones(len(S_idx))
	
		# save asynchrony (NaN means that response was not assigned)
		if (S_idx.size != 0 and R_idx.size != 0):
			lin_ind = np.ravel_multi_index((S_idx,R_idx),differences.shape)
			asyn[R_idx] = differences.ravel()[lin_ind]
	
	# Output
	output = pd.DataFrame({'asyn':asyn,'assigned_stim':assigned_stim})
	return output


#%% Error_Handling_For_Invalid_Trials. //AGREGAR COMENTARIO.
# Function to errors handling. Return a tuple.
# asyn_df --> dataframe from function Compute_Asyn. resp_times --> list with the response times. max_stim_for_first_resp --> maximum number of stimulus for first response. 
def Error_Handling(asyn_df, resp_times):
	
	max_stim_for_first_resp = 5	# Maximum number of stimulus for first response
	
	# Determine number of stimulus and responses registered.
	N_resp = len(resp_times)
	assigned_stim = asyn_df['assigned_stim'].values
	assigned_stim_NFR_filtered = []
	
	try: 
		if N_resp > 0: # If there were any response.

			# Find first stimulus with a decent response.
			first_assigned_stim = next(x for x in assigned_stim if x>=0)
			# If the first assigned stimulus doesn't much with any of the first stimulus, then re-do the trial.
			if first_assigned_stim >= max_stim_for_first_resp:			
				error_label = 'Tipo NFR'
				error_type = 'NoFirstResp'
				raise Error 

			# Find non assigned responses.
			if any(assigned_stim==-1):
				error_label = 'Tipo NAR'
				error_type = 'NonAssignedResp'
				raise Error

			# Find non assigned stimuli
			for i in range (len(assigned_stim)):
				if (assigned_stim[i] >= max_stim_for_first_resp):
					assigned_stim_NFR_filtered.append(assigned_stim[i])
			if (any(np.diff(assigned_stim_NFR_filtered)!=1) or assigned_stim_NFR_filtered[0] != max_stim_for_first_resp):
				error_label = 'Tipo SS'
				error_type = 'SkipStim'
				raise Error

			# If the code got here, then the trial is valid!
			valid_trial = 1
			error_label = ''
			error_type = 'NoError'                    

		else: # If there were no responses.
			# Trial is not valid! then:
			error_label = 'Tipo NR'
			error_type = 'NoResp'  
			raise Error

	except (Error):
		# Trial is not valid! then:
		valid_trial = 0
		
	return error_label, error_type, valid_trial


#%% Unfinished_Files
# Procedure to change names in unfinished files.
# subject_number --> int (ej: 1). n_block --> int (ej: 0). n_blocks --> int (ej: 2).
def Unfinished_Files(path, s_number, n_block, n_blocks):

	file_names_list = []
	original_path = os.getcwd()
	os.chdir(path)
	for block in range(n_block,n_blocks):
		file_names = glob.glob('S'+s_number+"*-block"+str(block)+"*")
		file_names_list = file_names_list + file_names
		
	for file in os.listdir():
		for searched_file in file_names_list:
			if (searched_file == file):
				src = file
				dst = 'unfinished' + file
				os.rename(src,dst)
	os.chdir(original_path)

	return

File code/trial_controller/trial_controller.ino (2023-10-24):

//Un timer controla dos pines de salida
//Estímulo: seno -pin 11 (OC1A)- Van Vugt script adaptation. pin 12: OC1B 
//Feedback: un timer controla dos pines:  seno -pin 5 (OC3A) y pin2 (OC3B) - Van Vugt script adaptation. pin 3: OC3C, pin 2: OC3B 
//trial eterno (sin Matlab)
//Manda estímulo al pin 11 y al pin 12 (timer 1)
//y feedback al pin 5 y al pin 2 (timer 3)

#define stimPinR 12   //ESTÍMULO EN PIN 12 ENVIADO POR EL TIMER 1 (En función initTimers).
#define stimPinL 11   //ESTÍMULO EN PIN 11 ENVIADO POR EL TIMER 1 (En función initTimers).
#define fdbkPinR 2    //FEEDBACK EN PIN 2 ENVIADO POR EL TIMER 3 (En función initTimers).
#define fdbkPinL 5    //FEEDBACK EN PIN 2 ENVIADO POR EL TIMER 3 (En función initTimers).
#define noisePinR 9   //RUIDO BLANCO (Comparte pin con noisePinL)
#define noisePinL 9   //RUIDO BLANCO (Comparte pin con noisePinR)
#define pinVG A11     //VALOR DE 0V VIRTUAL GENERADO POR EL SHIELD PARA LA SENOIDAL. 

#define LFSR_INIT  0xfeedfaceUL   //ES UN VALOR TOMADO DE INTERNET PARA LA RUTINA DE RUIDO BLANCO.
#define LFSR_MASK  ((unsigned long)( 1UL<<31 | 1UL <<15 | 1UL <<2 | 1UL <<1  ))   //SE UTILIZA TAMBIÉN PARA LA RUTINA DE RUIDO BLANCO.

//http://sphinx.mythic-beasts.com/~markt/ATmega-timers.html
boolean stimRight=true;  //pin12 - timer 1, channel B: right. TRUE: CARGA UN VALOR DE LA TABLA DEL SENO EN EL REGISTRO DE COMPARACIÓN DEL TIMER1 OCR1B
boolean stimLeft=true;  //pin11 - timer 1, channel A: left.   TRUE: CARGA UN VALOR DE LA TABLA DEL SENO EN EL REGISTRO DE COMPARACIÓN DEL TIMER1 OCR1A
boolean fdbkRight=true; //pin2 - timer 3, channel B: right.   TRUE: CARGA UN VALOR DE LA TABLA DEL SENO EN EL REGISTRO DE COMPARACIÓN DEL TIMER1 OCR3B
boolean fdbkLeft=true;  //pin5 - timer 3, channel A: left.    TRUE: CARGA UN VALOR DE LA TABLA DEL SENO EN EL REGISTRO DE COMPARACIÓN DEL TIMER1 OCR3A
boolean noise = false;                                      //SE UTILIZA EN LA INTERRUP DEL TIMER 2 PARA LA GENERACIÓN DEL RUIDO BLANCO

unsigned long int t=0;
long int prevStim_t=0;  //UTILIZADO EN LOOP() PARA EL CÁLCULO DE TIEMPO PARA EL ENVÍO DEL ESTÍMULO.
long int prevFdbk_t=0;  //UTILIZADO EN LA FUNCIÓN GET_PARAMETERS() EN EL CÁLCULO DE TIEMPO PARA LA RECEPCIÓN DE RESPUESTA POR PULSADOR
boolean stim_flag=false;//TRUE: LA VARIABLE AUX1 TOMA EL VALOR DE LA TABLA DE LA SENOIDAL
boolean perturb_flag1=false;//UTILIZADO EN PHASE SHIFT PERTURBACIÓN
boolean perturb_flag2=false;//UTILIZADO EN PHASE SHIFT PERTURBACIÓN
boolean fdbk_flag=false;//TRUE: LA VARIABLE AUX3 TOMA EL VALOR DE LA TABLA DE LA SENOIDAL

unsigned int stimFreq = 440;//(C6) // defines the frequency (i.e., pitch) of the tone (in Hz)
unsigned int fdbkFreq = 660;//(C6) // defines the frequency (i.e., pitch) of the tone (in Hz)

int vg = 0; //VALOR EN ENTERO DE LA MEDICIÓN DEL 0V VIRTUAL ENTREGADO POR EL SHIELD, ESCALADO A 10BIT (1024)
int read_vg = 0;  //TOMA SU VALOR DE LA FUNCIÓN READVIRTUALGROUND()
int amplitude = 120 ;//125;//1;  //SE USA EN VARIOS LADOS. TODAVÍA NO SÉ PARA QUE ES?????????????????????
int cycle_counter=0;
int num_cycles=3;
unsigned int max_num_cycles = 4,  min_num_cycles = 2; //(variable global)

int transitorio = 5;
int sensorIzqPin=A9;    //sensor de la izquierda
int voltajeSensorIzq;
//int voltajeSensorDer;
unsigned int NStim;
unsigned int stimNumber = 1;
unsigned int respNumber = 1;
//unsigned long t;
//unsigned long prevStim_t = 0;
unsigned long prevResp_t = 0;
unsigned long perturbBip_t;
unsigned int perturbBip;
unsigned int perturbationDone;
unsigned int perturbSize;
unsigned voltajeSampleCounter = 0;
unsigned long prevVoltajeSample_t = 0;
unsigned int *voltajeSensor;

int sensorThreshold = 50;
boolean voltajeSensorIzq_flag = false;
//boolean voltajeSensorDer_flag = false;
boolean readVoltajeSensorOn = false; // true;
boolean dosMuestrasXmili_flag = false;
//Duración del Tap. La cantidad total de milisegundos en los que el sensor registra la fuerza es: "tiempo1000HZ" + "tiempo500HZ"
int tiempo1000HZ=100; //milisegundos luego del tap en los que el sensor registra con una frecuencia de sampleo de 1KHz 
int tiempo500HZ=160; //milisegundos luego del finalizado tiempo1000 en los que el sensor registra con una frecuencia de sampleo de 500 Hz  


////Store data in memory
char *eventName;
unsigned int *eventNumber;
unsigned long *eventTime;
unsigned int eventCounter = 0;

//

uint16_t phaseIncrementStim = 0;  // 16 bit delta     //ESTOS CUATRO SE USAN PARA MODIFICAR EL INDEX DEL ARREGLO DE LA SEÑAL SENOIDAL, PERO NO ENTIENDO COMO FUNCIONA. HACE UN CORRIMIENTO????
uint16_t phaseIncrementFdbk = 0; // 16 bit delta
uint16_t phaseAccumulatorStim = 0;  // 16 bit accumulator
uint16_t phaseAccumulatorFdbk = 0; // 16 bit accumulator
int stim_counter; //VA AUMENTANDO EN LA INTERRUPCIÓN DEL TIMER1 Y SE COMPARA CON STIM_DURATION_CYCLES (DURACIÓN DEL ESTÍMULO). CUANDO TERMINA EL CICLO SE RESETEA.
int fdbk_counter; //VA AUMENTANDO EN LA INTERRUPCIÓN DEL TIMER3 Y SE COMPARA CON FDBK_DURATION_CYCLES (DURACIÓN DEL ESTÍMULO). CUANDO TERMINA EL CICLO SE RESETEA.

// DDS resolution
const uint32_t freq_samp = 31180; // 16MHz/513 porque ahora el pin está en modo 9 bits
const uint16_t resolution_DDS = pow(2,16)/freq_samp;


//AGREGO
uint16_t FDBK_DURATION_CYCLES = 23; // feedback duration (cycles).  //CICLOS DE DURACIÓN DEL CICLO
uint16_t STIM_DURATION_CYCLES = 23; // stimulus duration (cycles)   //CICLOS DE DURACIÓN DEL ESTÍMULO
#define STIM_DURATION 50 //stimulus duration (milliseconds)         //NO ES UTILIZADO
#define FDBK_DURATION 50 //este lo agrego yo                        //NO ES UTILIZADO
#define ANTIBOUNCE (0.5*isi)//minimum interval between responses (milliseconds)
boolean allow;  //CUANDO ALLOW ES FALSE, SE REGISTRA EL EVENTO DEL TRIAL
int fdbk;       //REGISTRA EL VALOR DE ENTRADA DEL PIN QUE LEE LA RESPUESTA DEL SUJETO DE ESTUDIO
int i;
unsigned int stim_number;     //REGISTRA EL NÚMERO DE ESTÍMULO
unsigned int fdbk_number;     //REGISTRA EL NÚMERO DE FEEDBACK
unsigned int *event_number;   //ENTIENDO QUE ES UN PUNTERO PARA RECORRER UN ARREGLO CON EL NÚMERO DE EVENTO
char *event_name;             //ENTIENDO QUE ES UN PUNTERO PARA RECORRER UN ARREGLO CON EL NOMBRE DEL EVENTO.
unsigned long *event_time;    //ENTIENDO QUE ES UN PUNTERO PARA RECORRER UN ARREGLO CON LOS TIEMPOS DE CADA EVENTO.
unsigned int event_counter;   //ENTIENDO QUE ES UN ÍNDICE QUE SE UTILIZA PARA RECORRER LOS ESPACIOS DE MEMORIA INDICADOS POR LOS TRES PUNTEROS ANTERIORES.

unsigned int isi=500;   //INICIALIZACIÓN DEL PERÍODO DEL ESTÍMULO, EL VALOR UTILIZADO SE RECIBE POR PYTHON.
unsigned int prevISI=0; //AUXILIAR PARA GUARDAR PERÍODO, EN EXPERIMENTO DE PERTURBACIÓN CON PHASE SHIFT.
unsigned int n_stim=3;  //Entiendo que son valores iniciales por las dudas //NO ENTIENDO BIEN PARA QUE SE USA ESTA VARIABLE, PARECIERA QUE PARA INDICAR CUÁL VA A SER EL NÚMERO TOTAL DE ESTÍMULOS
int perturb_size=0;     //TIEMPO DE PERTURBACIÓN QUE MODIFICA AL ISI(PERÍODO). ES UN INT, PORQUE EL DATO VIENE DE PYTHON Y PUEDE TENER SIGNO. 
unsigned int perturb_bip=0;   //SE ENVÍA VALOR DESDE PYTHON PARA INDICAR EN QUE BEEP SE VA A REALIZAR UNA PERTURBACIÓN EN EL ESTÍMULO.
unsigned int perturb_type=0;  //SELECCIONA EL TIPO DE PERTURBACIÓN 0->S(STEP CHANGE), 1->(PHASE SHIFT).
#define INPUTPIN A9   //DEFINICIÓN DEL PIN DE ENTRADA DE RESPUESTA DEL USUARIO.
char message[20];     //NO ENTIENDO SI SE ESTÁ USANDO, NO LO VEO PUESTO EN PROGRAMA EN FORMATO ARREGLO.  
boolean SR=false, SL=false, FR=false, FL=false, NR=false, NL=false; //ESTÁN DENTRO DE UN SWITCH CASE, TODAVÍA NO ENTIENDO PARA QUE SE USAN.

//////////// Set up lookup table for waveform generation
// sine wavefunction
static const uint8_t  sineTable[] PROGMEM = {   //UTILIZA PROGMEM PARA QUE LA TABLA SE GUARDE EN LA MEMORIA FLASH EN VEZ DE EN LA SRAM (ESTA ÚLTIMA ES VOLÁTIL)
0x80,0x83,0x86,0x89,0x8c,0x8f,0x92,0x95,
0x98,0x9c,0x9f,0xa2,0xa5,0xa8,0xab,0xae,
0xb0,0xb3,0xb6,0xb9,0xbc,0xbf,0xc1,0xc4,
0xc7,0xc9,0xcc,0xce,0xd1,0xd3,0xd5,0xd8,
0xda,0xdc,0xde,0xe0,0xe2,0xe4,0xe6,0xe8,
0xea,0xec,0xed,0xef,0xf0,0xf2,0xf3,0xf5,
0xf6,0xf7,0xf8,0xf9,0xfa,0xfb,0xfc,0xfc,
0xfd,0xfe,0xfe,0xff,0xff,0xff,0xff,0xff,
0xff,0xff,0xff,0xff,0xff,0xff,0xfe,0xfe,
0xfd,0xfc,0xfc,0xfb,0xfa,0xf9,0xf8,0xf7,
0xf6,0xf5,0xf3,0xf2,0xf0,0xef,0xed,0xec,
0xea,0xe8,0xe6,0xe4,0xe2,0xe0,0xde,0xdc,
0xda,0xd8,0xd5,0xd3,0xd1,0xce,0xcc,0xc9,
0xc7,0xc4,0xc1,0xbf,0xbc,0xb9,0xb6,0xb3,
0xb0,0xae,0xab,0xa8,0xa5,0xa2,0x9f,0x9c,
0x98,0x95,0x92,0x8f,0x8c,0x89,0x86,0x83,
0x80,0x7c,0x79,0x76,0x73,0x70,0x6d,0x6a,
0x67,0x63,0x60,0x5d,0x5a,0x57,0x54,0x51,
0x4f,0x4c,0x49,0x46,0x43,0x40,0x3e,0x3b,
0x38,0x36,0x33,0x31,0x2e,0x2c,0x2a,0x27,
0x25,0x23,0x21,0x1f,0x1d,0x1b,0x19,0x17,
0x15,0x13,0x12,0x10,0x0f,0x0d,0x0c,0x0a,
0x09,0x08,0x07,0x06,0x05,0x04,0x03,0x03,
0x02,0x01,0x01,0x00,0x00,0x00,0x00,0x00,
0x00,0x00,0x00,0x00,0x00,0x00,0x01,0x01,
0x02,0x03,0x03,0x04,0x05,0x06,0x07,0x08,
0x09,0x0a,0x0c,0x0d,0x0f,0x10,0x12,0x13,
0x15,0x17,0x19,0x1b,0x1d,0x1f,0x21,0x23,
0x25,0x27,0x2a,0x2c,0x2e,0x31,0x33,0x36,
0x38,0x3b,0x3e,0x40,0x43,0x46,0x49,0x4c,
0x4f,0x51,0x54,0x57,0x5a,0x5d,0x60,0x63,
0x67,0x6a,0x6d,0x70,0x73,0x76,0x79,0x7c
};

// ---- Hasta aca definiciones, etc ------------------------------------------------------------------------------


ISR(TIMER1_OVF_vect) {
  // wavetable lookup index (upper 8 bits of the accumulator)   //indice de búsqueda de tabla de ondas (8 bits superiores del acumulador)
  uint8_t index1 = 0;   //ÍNDICE PARA EL RECORRIDO DE LA TABLA DEL SENO EN LA MEMORIA FLASH
  uint16_t aux1;        //AUXILIAR PARA GUARDAR EL VALOR PWM DE LA TABLA SENO QUE SE RECUPERA DE LA MEMORIA FLASH
  
  // Update accumulator
  phaseAccumulatorStim += phaseIncrementStim;
  index1 = phaseAccumulatorStim >> 8;                     //GUARDA EN INDEX1 EL EL BYTE MÁS SIGNIFICATIVO DE phaseAccumulatorStim.
  if(index1 <= (phaseIncrementStim >>8))  stim_counter++; // counter aumenta cuando index1 resetea

  OCR1A = vg;   //CARGAN EN EL REGISTRO OCR1A EL VALOR EN ENTERO DE LA MEDICIÓN DEL 0V VIRTUAL ENTREGADO POR EL SHIELD, ESCALADO A 10BIT (1024)?? ES PARA DETECTAR EL CRUCE POR CERO?? LA CANTIDAD DE BITS DE LOS REGISTROS NO COINCIDEN.
  OCR1B = vg;   //CARGAN EN EL REGISTRO OCR1B EL VALOR EN ENTERO DE LA MEDICIÓN DEL 0V VIRTUAL ENTREGADO POR EL SHIELD, ESCALADO A 10BIT (1024)?? ES PARA DETECTAR EL CRUCE POR CERO?? LA CANTIDAD DE BITS DE LOS REGISTROS NO COINCIDEN.

    
// if (t-prevStim_t<STIM_DURATION){
  if (stim_counter< STIM_DURATION_CYCLES){ // VERIFICA SI stim_counter ES MENOR A LA DURACIÓN DEL ESTÍMULO.
  
   if(stim_flag==true){                             //HABILITA QUE LA VARIABLE AUX1 TOME EL VALOR DE LA TABLA DE LA SENOIDAL
    aux1 = pgm_read_byte(&sineTable[index1]);       //ESTA FUNCIÓN SE UTILIZA PARA LEER UN BYTE UBICADO EN LA MEMORIA FLASH (EN ESTE CASO LE PASA LA DIRECCIÓN DE MEMORIA ADONDE ESTÁ APUNTANDO EL ÍNDICE)
  // Read oscillator value for next interrupt
    
    if (stimLeft==true)  OCR1A = aux1;    //CARGA EL VALOR ACTUAL DEL PWM PARA LA CONSTRUCCIÓN DE LA SENOIDAL EN EL REGISTRO DE COMPARACIÓN OCR1A

    if (stimRight==true)   OCR1B = aux1;  //CARGA EL VALOR ACTUAL DEL PWM PARA LA CONSTRUCCIÓN DE LA SENOIDAL EN EL REGISTRO DE COMPARACIÓN OCR1B
  
  }  
 }

else  stim_flag=false;    //SI stim_counter ES >= A LA DURACIÓN DEL ESTÍMULO, stim_flag = FALSE Y YA NO SE MODIFICAN LOS REGISTROS OCR1A Y OCR1B

}


ISR(TIMER3_OVF_vect) {
  // wavetable lookup index (upper 8 bits of the accumulator)
  uint8_t index3 = 0;   //ÍNDICE PARA EL RECORRIDO DE LA TABLA DEL SENO EN LA MEMORIA FLASH
  uint16_t aux3;        //AUXILIAR PARA GUARDAR EL VALOR PWM DE LA TABLA SENO QUE SE RECUPERA DE LA MEMORIA FLASH
  
  // Update accumulator
  phaseAccumulatorFdbk += phaseIncrementFdbk;
  index3 = phaseAccumulatorFdbk >> 8;                     //GUARDA EN INDEX3 EL EL BYTE MÁS SIGNIFICATIVO DE phaseAccumulatorFdbk.
  if(index3 <= (phaseIncrementFdbk >>8))  fdbk_counter++; // counter aumenta cuando index3 resetea

  OCR3A = vg; //CARGAN EN EL REGISTRO OCR3A EL VALOR EN ENTERO DE LA MEDICIÓN DEL 0V VIRTUAL ENTREGADO POR EL SHIELD, ESCALADO A 10BIT (1024)?? ES PARA DETECTAR EL CRUCE POR CERO?? LA CANTIDAD DE BITS DE LOS REGISTROS NO COINCIDEN.
  OCR3B = vg; //CARGAN EN EL REGISTRO OCR3B EL VALOR EN ENTERO DE LA MEDICIÓN DEL 0V VIRTUAL ENTREGADO POR EL SHIELD, ESCALADO A 10BIT (1024)?? ES PARA DETECTAR EL CRUCE POR CERO?? LA CANTIDAD DE BITS DE LOS REGISTROS NO COINCIDEN.

//  if (t-prevFdbk_t<FDBK_DURATION){
  if (fdbk_counter< FDBK_DURATION_CYCLES){        // VERIFICA SI fdbk_counter ES MENOR A LA DURACIÓN DEL ESTÍMULO.
    
    if(fdbk_flag==true){                          //HABILITA QUE LA VARIABLE AUX3 TOME EL VALOR DE LA TABLA DE LA SENOIDAL
      aux3 = pgm_read_byte(&sineTable[index3]);   //ESTA FUNCIÓN SE UTILIZA PARA LEER UN BYTE UBICADO EN LA MEMORIA FLASH (EN ESTE CASO LE PASA LA DIRECCIÓN DE MEMORIA ADONDE ESTÁ APUNTANDO EL ÍNDICE)
    // Read oscillator value for next interrupt
   
      if (fdbkLeft==true)  OCR3A = aux3;          //CARGA EL VALOR ACTUAL DEL PWM PARA LA CONSTRUCCIÓN DE LA SENOIDAL EN EL REGISTRO DE COMPARACIÓN OCR3A
  
      if (fdbkRight==true)   OCR3B = aux3;        //CARGA EL VALOR ACTUAL DEL PWM PARA LA CONSTRUCCIÓN DE LA SENOIDAL EN EL REGISTRO DE COMPARACIÓN OCR3B
    
    }  
   }
  
  else  fdbk_flag=false;                          //SI fdbk_counter ES >= A LA DURACIÓN DEL ESTÍMULO,fdbk_flag = FALSE Y YA NO SE MODIFICAN LOS REGISTROS OCR3A Y OCR3B
  
}


ISR(TIMER2_OVF_vect){   //TIMER PARA RUTINA DE RUIDO BLANCO
  OCR2A = vg;

  if(noise==true){
    if(cycle_counter==0)
      // setea OCR arriba durante la primera mitad del período de ruido
      OCR2B = vg+amplitude;
    if(cycle_counter==round(num_cycles/2.0))
      // setea OCR abajo durante la segunda mitad del período de ruido
      OCR2B = vg-amplitude;
    if(cycle_counter==num_cycles-1){
      // vuelve a empezar, nuevo período de ruido
      num_cycles = generateNoise();
      cycle_counter = -1;
    }
    cycle_counter++;
  }
//  Serial.println(cycle_counter);
}
//máximo número de ciclos consecutivos del timer

// --------- Primer Void ---------------------------------------------
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
void loop() {

  if(allow == false){   //ALLOW = FALSE, PERMITE QUE SE LEA UN MENSAJE DESDE PYTHON
      
    //just in case, clear incoming buffer once read
    Serial.flush();
        
        //Turn on noise
    SoundSwitch('n',120,true,true);     //ENVÍA SONIDO BLANCO A AMBOS OÍDOS

    get_parameters();   //LEE MENSAJE DE PYTHON DESDE EL SERIAL HASTA QUE ENCUENTRA UNA "X". EL ALGORITMO INTERPRETA LA "X" COMO FIN DE MENSAJE DESDE PYTHON. 
    prevISI = isi;      //GUARDA EN VARIABLE AUXILIAR prevISI EL PERÍODO ORIGINAL isi 
    allow = true;       //PONE EL FLAG ALLOW EN TRUE, PARA QUE NO SE LEA UN NUEVO DATO HASTA QUE NO SE PROCESE EL ACTUAL.

    stim_number = 0;    //INICIALIZA VARIABLE
    fdbk_number = 0;    //INICIALIZA VARIABLE
    event_counter = 0;  //INICIALIZA VARIABLE
    perturb_flag1 = false;
    perturb_flag2 = false;
    prevVoltajeSample_t = 0;
    voltajeSensorIzq_flag = false;
    voltajeSampleCounter = 0;

    event_name = (char*) calloc(3*n_stim,sizeof(char));                     //RESERVA UNA MEMORIA PARA 3*n_stim ELEMENTOS DE TAMAÑO sizeof(char)(CHAR = 1 BYTE). INICIALIZA EL BLOQUE DE MEMORIA EN 0. DEVUELVE UN PUNTERO AL PRIMER CHAR EN event_name. 
    event_number = (unsigned int*) calloc(3*n_stim,sizeof(unsigned int));   //RESERVA UNA MEMORIA PARA 3*n_stim ELEMENTOS DE TAMAÑO sizeof(unsigned int)(unsigned int = 4 BYTEs). INICIALIZA EL BLOQUE DE MEMORIA EN 0. DEVUELVE UN PUNTERO AL PRIMER UNSIGNED INT EN event_number.
    event_time = (unsigned long*) calloc(3*n_stim,sizeof(unsigned long));   //RESERVA UNA MEMORIA PARA 3*n_stim ELEMENTOS DE TAMAÑO sizeof(unsigned long)(unsigned long = 4 BYTEs). INICIALIZA EL BLOQUE DE MEMORIA EN 0. DEVUELVE UN PUNTERO AL PRIMER UNSIGNED LONG EN event_time.
    
    voltajeSensor = (unsigned int*) calloc(n_stim*tiempo1000HZ, sizeof(unsigned int));  //   taps seguro, quizás más
}
else{               //ALLOW = TRUE, CORRE EL TRIAL ENVIADO EN EL MENSAJE DE PYTHON
    t = millis();     //REGISTRA EN t EL TIEMPO ACTUAL

    //Turn on noise
    //SoundSwitch('n',amplitude,NL,NR);     //ENVÍA SONIDO BLANCO A AMBOS OÍDOS

    //Perturbation
    if (stim_number == perturb_bip){
      if ((perturb_type == 0 or perturb_type == 1) and perturb_flag1 == false){
        prevISI = isi;
        isi += perturb_size;
        perturb_flag1 = true;
      }
    }
    if (stim_number == perturb_bip + 1){
      if (perturb_type==1 and perturb_flag2==false) {
        isi = prevISI;
        perturb_flag2 = true;
      }
    }
    
    //Send stimulus 
    if ((t-prevStim_t)>= isi && stim_flag==false) { //enciende el sonido //SI PASÓ UN LAPSO DE TIEMPO MAYOR AL PERÍODO ENTRE ESTÍMULOS Y stim_flag == false
      SoundSwitch('s', stimFreq, SL, SR);                               //ENVÍA ESTÍMULO
      prevStim_t=t;                                                     //REGISTRA EL TIEMPO ACTUAL EN prevStim, PARA VOLVER A CONTAR EL PERÍODO ENTRE ESTÍMULOS
      stim_flag=true;                                                   //DESHABILITA LA POSIBILIIDAD DE ENVIAR UN NUEVO ESTÍMULO
      save_data('S', stim_number, t);                                   //GUARDA EL NÚMERO DE ESTÍMULO Y EL TIEMPO AL CUÁL OCURRIÓ.
    }
    
    //Read response                                             //ESTE BLOQUE IF, ES PARA ENVIAR LA RESPUESTA AL SUJETO
    if ((t - prevFdbk_t) > ANTIBOUNCE && fdbk_flag==false) {    //SE APLICA UN FILTRO ANTIREBOTE, PARA EVITAR QUE SE REGISTRE MÁS DE UNA RESPUESTA
      fdbk = digitalRead(INPUTPIN);                             //SE LEE LA RESPUESTA DEL SUJETO DESDE EL PIN DEL ARDUINO
      if (fdbk == HIGH){                                        //EVALÚA SI EL PIN ESTÁ EN 1
        SoundSwitch('f', fdbkFreq, FL, FR);                     //ENVÍA SONIDO DE FEEDBACK AL SUJETO
        prevFdbk_t=t;                                           //REGISTRA EL TIEMPO ACTUAL EN prevFdbk,PARA UTILIZARLO EN EL FILTRO ANTIREBOTE ((t - prevFdbk_t) > ANTIBOUNCE)
        fdbk_flag=true;                                         //DESHABILITA LA POSIBILIIDAD DE REGISTRAR UNA NUEVA RESPUESTA
        save_data('R', fdbk_number, t);  
        voltajeSensorIzq_flag = true;                    //GUARDA EL NÚMERO DE FEEDBACK Y EL TIEMPO AL CUÁL OCURRIÓ.
      }
    }



    /////Read sensor voltaje


    //Sensor. Intervalo de taps en el que la lectura del sensor está habilitada.
 //   if (stimNumber > (transitorio) && (t - prevStim_t) >= (isi / 2)) { //el sensor es habilitado para registrar cuando faltan tapsPrePertToBeRecorded taps para la perturbación
 //     readVoltajeSensorOn = true;
 //   }

    //if (stimNumber > (perturbBip + 14) && (t - prevStim_t) >= (isi / 2)) { //el sensor se deshabilita 14 taps y medio después de la perturbación 
    //if (stimNumber > (perturbBip + 8) && (t - prevStim_t) >= (isi / 2)) { //el sensor se deshabilita 8 taps y medio después de la perturbación. Usar con NStim=23 en Matlab. Registra la fuerza de 16 taps
    //  if (stimNumber > (perturbBip + tapsPosPertToBeRecorded) && (t - prevStim_t) >= (isi / 2)) { //el sensor se deshabilita 12 taps y medio después de la perturbación. Usar con NStim=27 en Matlab. Registra la fuerza de 20 taps 
    //  readVoltajeSensorOn = false;
    //}

    //1kHz sampling

//    if (stimNumber > (transitorio) && (t - prevVoltajeSample_t) >= 1 && voltajeSensorIzq_flag == true && readVoltajeSensorOn == true && dosMuestrasXmili_flag == false) { //almacena el valor de entrada del sensor, un dato por milisegundo
    if (stim_number > (transitorio) && voltajeSensorIzq_flag == true && dosMuestrasXmili_flag == false) { 
      voltajeSensor[voltajeSampleCounter] = analogRead(sensorIzqPin);
      //tiempo[osc_counter]=t;
      voltajeSampleCounter++;
      dosMuestrasXmili_flag = true;
      prevVoltajeSample_t = t;
    }

    if ((t - prevVoltajeSample_t) >= 1) {
      dosMuestrasXmili_flag = false;
    } 

//Stop sampling at 1KHz
//    if ((t - prevResp_t) >= tiempo1000HZ && (voltajeSensorIzq_flag == true) && readVoltajeSensorOn == true && dosMuestrasXmili_flag == false) { //intervalo de tiempo durante el cual el sensor registra cada tap  (50 ms)
    if ((t - prevFdbk_t) >= tiempo1000HZ && (voltajeSensorIzq_flag == true)) { //intervalo de tiempo durante el cual el sensor registra cada tap  (50 ms)
//      voltajeSensor[voltajeSampleCounter] = 1800; //terminador. Cuando cambia la frecuencia de muestreo
      voltajeSampleCounter++;
      voltajeSensorIzq_flag = false;
      //voltajeSensorDer_flag = false;
      dosMuestrasXmili_flag = true;
    }

    ////perturbation
    if (stimNumber == perturbBip && perturbationDone == false) {
      //step change or first perturbation of phase shift
      isi += perturbSize;
      perturbationDone = true;
      
    }



    //End trial
    //allow one more period (without stimulus)
    if ((stim_number >= n_stim) && ((t - prevStim_t) >= (0.5 * isi))) {
      for (i = 0; i<event_counter; i++) {
        sprintf(message,"%c %d %ld",event_name[i],event_number[i],event_time[i]);
        
        serial_print_string(message);
      }
     //  Serial.println("E");  //send END message

      allow = false;
      
      for (i = 0; i < voltajeSampleCounter; i++) { //send sensor data to Matlab
        // sprintf(message,"%d: %ld;",osc[i],tiempo[i]);           //%d decimal integer
        sprintf(message, "V %d %d", i, voltajeSensor[i]);         //%d decimal integer
//        Serial.println(message);
        serial_print_string(message);
      }
      Serial.println("E");  //send END message

      //turn off noise 
      SoundSwitch('s',1,false,false);
      SoundSwitch('f',1,false,false);
      SoundSwitch('n',120,false,false); 

      free(event_name);
      free(event_number);
      free(event_time);
      free(voltajeSensor); 
    }

  }
  
}
